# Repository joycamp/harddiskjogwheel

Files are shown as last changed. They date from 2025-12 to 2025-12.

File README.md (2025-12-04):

# Hard Disk Jog Wheel

Turn a hard disk drive (or any rotary mechanism) into a wireless MIDI jog wheel for video or audio editing using an ESP32-S3 and AS5600 magnetic encoder.

This project creates a Bluetooth Low Energy (BLE) MIDI device that sends relative jog wheel commands compatible with Logic Pro, Final Cut Pro (via Command Post), and other DAWs.

## Features

- **Wireless BLE MIDI** - No cables needed, works with macOS Audio MIDI Setup
- **AS5600 Magnetic Encoder** - Contactless, high-resolution rotation sensing
- **Relative MIDI Mode** - Proper jog wheel behavior with proportional speed control
- **Button Support** - Additional MIDI CC for button press/release
- **Configurable Sensitivity** - Adjustable rotation thresholds and scaling

## Hardware Requirements

- **ESP32-S3** development board (e.g., ESP32-S3-DevKitC-1)
- **AS5600** magnetic position sensor (AMS AS5600)
- **Magnet** - Diametrically magnetized magnet (typically 6-8mm diameter, 2-3mm thick)
- **Button** - Optional tactile button for additional control
- **Wiring** - Jumper wires, breadboard (or custom PCB)

## Hardware Connections

### AS5600 Magnetic Encoder
- **VCC** → 3.3V (ESP32-S3)
- **GND** → GND (ESP32-S3)
- **SDA** → GPIO 8
- **SCL** → GPIO 9

**Note:** The AS5600 operates at 3.3V logic levels, which matches the ESP32-S3 perfectly. No level shifters needed.

### Button (Optional)
- **One terminal** → GPIO 4
- **Other terminal** → GND

The code uses internal pull-up resistors, so no external pull-up needed.

### Magnet Positioning
- Place magnet **1-3mm** above the AS5600 sensor
- Ensure magnet is **centered** over the sensor
- Magnet should be **diametrically magnetized** (north-south poles on opposite sides)

## Software Setup

### 1. Install Arduino IDE

Download and install [Arduino IDE](https://www.arduino.cc/en/software) (version 1.8.19 or later).

### 2. Install ESP32-S3 Board Support

1. Open Arduino IDE
2. Go to **File > Preferences**
3. In "Additional Board Manager URLs", add:
   ```
   https://espressif.github.io/arduino-esp32/package_esp32_index.json
   ```
4. Go to **Tools > Board > Boards Manager**
5. Search for "ESP32" and install **"esp32 by Espressif Systems"** (version 3.3.3 or later)
6. Select your board: **Tools > Board > ESP32 Arduino > ESP32S3 Dev Module**

### 3. Install Required Libraries

Install these libraries via **Tools > Manage Libraries**:

#### Required Libraries:

1. **ESP32-BLE-MIDI** by max22-
   - Search for "ESP32-BLE-MIDI" in Library Manager
   - Install version compatible with ESP32-S3
   - GitHub: https://github.com/max22-/ESP32-BLE-MIDI

2. **NimBLE-Arduino** by h2zero
   - Search for "NimBLE-Arduino" in Library Manager
   - Install latest version
   - Required dependency for ESP32-BLE-MIDI
   - GitHub: https://github.com/h2zero/NimBLE-Arduino

#### Built-in Libraries (No Installation Needed):
- **Wire** - I2C communication (included with ESP32 core)
- **Arduino.h** - Core Arduino functions (included with ESP32 core)

### 4. Configure Board Settings

In Arduino IDE, configure these settings:

- **Tools > Board** → **ESP32S3 Dev Module**
- **Tools > USB Mode** → **Hardware CDC and JTAG** (for Serial debugging)
- **Tools > USB CDC On Boot** → **Enabled**
- **Tools > Partition Scheme** → **Default 4MB with spiffs** (or **Huge APP**)
- **Tools > Port** → Select your ESP32-S3 COM port

### 5. Upload the Sketch

1. Open `midijogwheelV2.ino` in Arduino IDE
2. Verify all settings are correct
3. Click **Upload**

**If upload fails:**
- Hold **BOOT** button on ESP32-S3
- Press and release **RESET** button
- Release **BOOT** button
- Immediately click Upload in Arduino IDE

### 6. Connect via Bluetooth

1. Open **Audio MIDI Setup** (Applications > Utilities on macOS)
2. Go to **Window > Show MIDI Studio**
3. Click the **"Configure Bluetooth"** icon (or go to **Window > Configure Bluetooth**)
4. Find **"ESP32-S3-TE!"** in the list
5. Click **Connect**

The device should now appear in your MIDI Studio and be available to Logic Pro, Final Cut Pro, and other applications.

## Configuration

### MIDI Settings

Edit these constants in `midijogwheelV2.ino`:

```cpp
const int MIDI_CHANNEL = 0;  // MIDI channel (0-15, 0 = channel 1)
const int JOG_CC = 60;       // CC number for jog wheel
const int BUTTON_CC = 61;    // CC number for button
```

### Sensitivity Settings

Adjust rotation sensitivity:

```cpp
const int ANGLE_THRESHOLD = 10;        // Minimum angle change to trigger MIDI (0-4095 scale)
const int MIN_RELATIVE_VALUE = 1;      // Minimum relative increment
const int MAX_RELATIVE_VALUE = 10;     // Maximum relative increment (lower = less sensitive)
const int RELATIVE_SCALE = 20;         // Scale factor (higher = less sensitive)
```

**Tips:**
- Lower `MAX_RELATIVE_VALUE` (e.g., 5) = less sensitive to fast spinning
- Higher `RELATIVE_SCALE` (e.g., 30) = overall less sensitive
- Lower `ANGLE_THRESHOLD` (e.g., 5) = more responsive to small movements

### Pin Configuration

If you need different GPIO pins:

```cpp
const int SDA_PIN = 8;      // AS5600 SDA pin
const int SCL_PIN = 9;      // AS5600 SCL pin
const int BUTTON_PIN = 4;   // Button pin
```

**Note:** ESP32-S3 supports I2C on any GPIO pins. Choose pins that don't conflict with your board's USB/JTAG pins.

### Device Name

Change the BLE device name:

```cpp
BLEMidiServer.begin("ESP32-S3-TE!");  // Change to your preferred name
```

**Note:** Keep the name short (max 29 characters) and avoid special characters that might cause issues.

## MIDI Protocol

### Jog Wheel (CC 60)

Uses **relative mode encoding**:
- **Clockwise rotation**: CC 60 = 1-63 (increment values, proportional to rotation speed)
- **Counter-clockwise rotation**: CC 60 = 65-127 (decrement values, proportional to rotation speed)
- **No movement**: No MIDI messages sent

Values scale with rotation speed:
- Slow rotation → small values (1-2 or 65-66)
- Fast rotation → larger values (up to MAX_RELATIVE_VALUE or 64+MAX_RELATIVE_VALUE)

### Button (CC 61)

- **Press**: CC 61 = 127
- **Release**: CC 61 = 0

## Usage with DAWs

### Logic Pro

1. Open Logic Pro
2. Go to **Logic Pro > Settings > MIDI**
3. Ensure your ESP32-S3 device is enabled
4. Use **Learn** function:
   - Right-click on transport controls or jog wheel
   - Select **"Learn MIDI Assignment"**
   - Rotate the jog wheel
   - Logic Pro will learn the MIDI CC message

### Final Cut Pro (via Command Post)

1. Install [Command Post](https://commandpost.fcp.cafe/)
2. Open Command Post preferences
3. Go to **MIDI** settings
4. Click **Learn** for the action you want to map
5. Rotate the jog wheel
6. Command Post will learn the MIDI assignment

**Note:** Ensure the device name in Command Post matches exactly what your ESP32-S3 advertises (default: "ESP32-S3-TE!").

### Other DAWs

Any DAW that supports MIDI CC learning should work. The device sends standard MIDI Control Change messages over BLE MIDI.

## Testing

### Serial Monitor

Open Serial Monitor (115200 baud) to see:
- AS5600 initialization status
- Angle readings and changes
- MIDI messages being sent
- Connection status

## Troubleshooting

### Device Not Appearing in Bluetooth Settings

- Ensure BLE MIDI is initialized (check Serial Monitor)
- Try disconnecting and reconnecting in Audio MIDI Setup
- Restart Audio MIDI Setup
- Check that no other device is using the same name

### AS5600 Not Responding (I2C Error)

- Check wiring: VCC→3.3V, GND→GND, SDA→GPIO8, SCL→GPIO9
- Verify magnet is positioned 1-3mm above sensor
- Check Serial Monitor for specific error codes
- Verify I2C address 0x36 is accessible (you can use any I2C scanner tool)

### MIDI Messages Not Working in DAW

- Verify device is connected in Audio MIDI Setup
- Check MIDI channel matches what DAW expects (default: channel 1)
- Ensure DAW has MIDI input enabled
- Try learning the MIDI assignment again
- Check Serial Monitor to confirm messages are being sent

### Too Sensitive / Not Sensitive Enough

- Adjust `MAX_RELATIVE_VALUE` (lower = less sensitive to fast spinning)
- Adjust `RELATIVE_SCALE` (higher = overall less sensitive)
- Adjust `ANGLE_THRESHOLD` (lower = more responsive)

### Upload Fails

- Use manual bootloader mode (hold BOOT, press RESET, release BOOT, upload)
- Try different USB cable (some are power-only)
- Try different USB port
- Close Serial Monitor before uploading
- Ensure no other program is using the serial port

## Project Structure

```
harddiskjogwheel/
├── midijogwheelV2.ino          # Main sketch
├── README.md                    # This file
├── LICENSE                      # MIT License
├── serial_monitor.py           # Python serial monitor script (optional)
└── .gitignore                  # Git ignore rules
```

## Libraries Used

### ESP32-BLE-MIDI
- **Author**: max22-
- **Purpose**: BLE MIDI server implementation for ESP32
- **Installation**: Arduino Library Manager → Search "ESP32-BLE-MIDI"
- **GitHub**: https://github.com/max22-/ESP32-BLE-MIDI
- **License**: Check repository for license information

### NimBLE-Arduino
- **Author**: h2zero
- **Purpose**: NimBLE BLE stack for Arduino/ESP32 (dependency of ESP32-BLE-MIDI)
- **Installation**: Arduino Library Manager → Search "NimBLE-Arduino"
- **GitHub**: https://github.com/h2zero/NimBLE-Arduino
- **License**: Apache 2.0

### Wire (Built-in)
- **Purpose**: I2C communication library
- **Included**: With ESP32 Arduino core
- **Documentation**: https://www.arduino.cc/reference/en/language/functions/communication/wire/

## License

MIT License - See LICENSE file for details.

## Credits

- ESP32-S3 by Espressif Systems
- AS5600 by AMS (Austria Micro Systems)
- ESP32-BLE-MIDI library by max22-
- NimBLE-Arduino by h2zero

## Contributing

Contributions welcome! Please open an issue or pull request on GitHub.

## Support

For issues, questions, or contributions, please use the GitHub Issues page.

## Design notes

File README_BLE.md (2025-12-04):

# BLE MIDI Setup for ESP32-S3

This version uses Bluetooth Low Energy (BLE) MIDI instead of USB MIDI, which works well on macOS/iOS.

## Library Installation

1. **Install ESP32-BLE-MIDI Library:**
   - Go to **Tools > Manage Libraries**
   - Search for "ESP32-BLE-MIDI"
   - Install "ESP32-BLE-MIDI" by lathoub (or max22-)

## Board Settings

- **Tools > USB Mode** → Can be "Hardware CDC and JTAG" (Serial will work!)
- **Tools > USB CDC On Boot** → "Enabled"

## Setup Steps

1. **Upload the BLE MIDI code** (`minimal_test_ble.ino`)

2. **Pair with macOS:**
   - Open **System Settings > Bluetooth**
   - Look for "ESP32-S3 MIDI"
   - Click **Connect**

3. **Add to Audio MIDI Setup:**
   - Open **Audio MIDI Setup** (Applications > Utilities)
   - Go to **Window > Show MIDI Studio**
   - The device should appear automatically after pairing
   - If not, click **"Rescan MIDI"**

4. **Test:**
   - Open Serial Monitor (115200 baud) to see status
   - The device sends CC60 = 1 every second when connected
   - Check Audio MIDI Setup to verify messages are being received

## Advantages of BLE MIDI

- ✅ Works wirelessly
- ✅ Native macOS/iOS support
- ✅ Serial debugging works (unlike USB-OTG mode)
- ✅ More reliable than USB MIDI on some boards
- ✅ Can connect to multiple devices

## Notes

- The device name is "ESP32-S3 MIDI" - look for this in Bluetooth settings
- You may need to pair it first in Bluetooth settings before it appears in MIDI Studio
- BLE MIDI has slightly higher latency than USB MIDI, but usually not noticeable

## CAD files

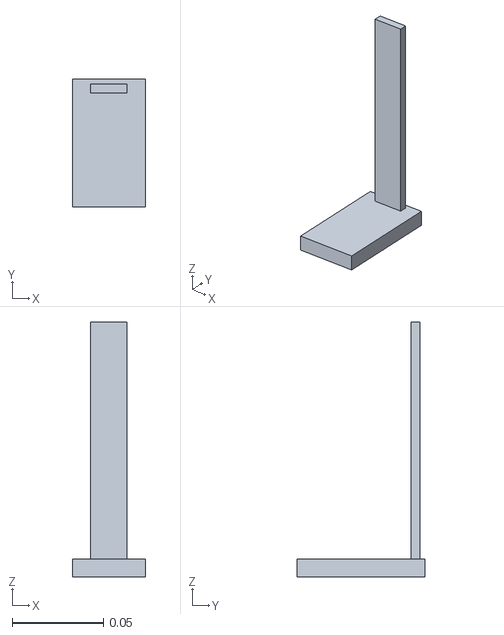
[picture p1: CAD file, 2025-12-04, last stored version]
models/armatureV3.obj
0.04 x 0.07 x 0.14

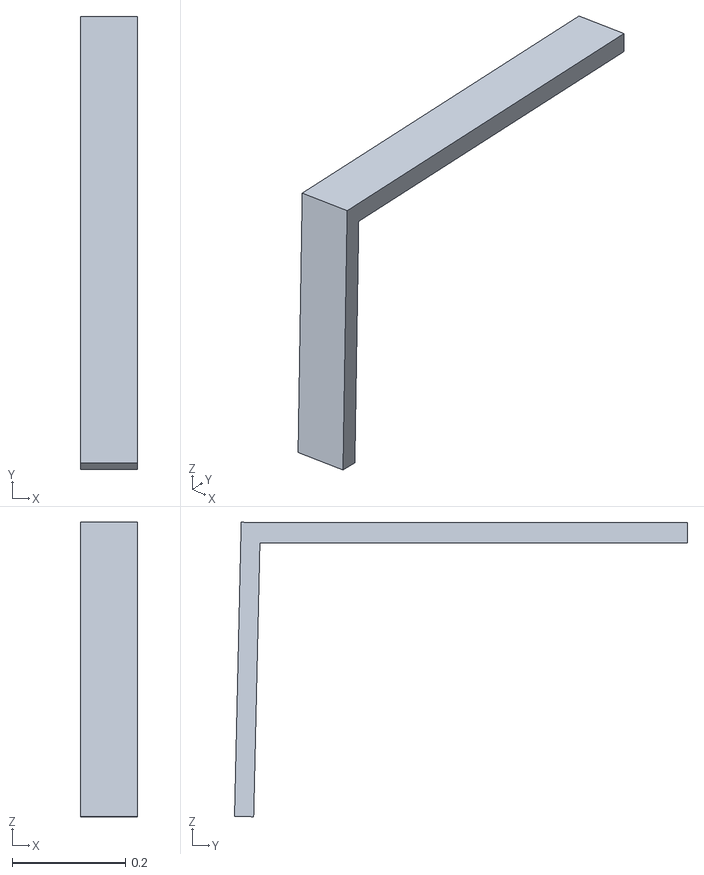
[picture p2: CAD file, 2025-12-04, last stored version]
models/armature2.stl
0.1 x 0.8 x 0.521

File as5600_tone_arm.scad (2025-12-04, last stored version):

//
// HDD jog wheel "tone arm" for Adafruit AS5600 (Adafruit 6357)
// Arm mounts at the left screw hole, treated as (0, 0)
// Spindle centre is at (spindle_dx, spindle_dy)
//
// All units in millimetres
//

// --------------------------
// Geometry inputs
// --------------------------

// Height from HDD lid to magnet top
magnet_above_lid = 3;          // 3 mm magnet on the hub

// Sensor gap you want between chip and magnet
sensor_gap = 2;                // 1 to 3 mm is ideal

// Board dimensions for Adafruit 6357 (approx, tweak if needed)
board_x = 20;   // along arm
board_y = 18;   // across arm
pcb_thickness = 1.6;
chip_above_pcb = 1.0;          // distance chip body top above PCB

// Tone arm geometry
arm_outer_diameter  = 8;
arm_inner_diameter  = 4;
headshell_length    = 26;      // region under sensor
headshell_width     = 22;
headshell_thickness = 3;

// Mount block geometry
base_block_length   = 26;
base_block_width    = 24;
base_block_height   = 10;
mount_hole_diameter = 3.5;     // M3 screw

// --------------------------
// Position of spindle relative to screw hole
// X to the right, Y up when looking at the lid
// Your measurements:
//   X = 65 mm
//   Y = 20 mm
// --------------------------

spindle_dx = 65;
spindle_dy = 20;

// --------------------------
// Derived heights
// --------------------------

// Magnet top relative to lid plane
magnet_top_z = magnet_above_lid;

// Chip height
chip_z       = magnet_top_z + sensor_gap;

// PCB bottom height so chip lands at chip_z
pcb_bottom_z = chip_z - chip_above_pcb - pcb_thickness / 2;

// Place underside of headshell just above PCB
headshell_z  = pcb_bottom_z + headshell_thickness / 2;

// Arm tube centre height
arm_centre_z = headshell_z + 2;   // small offset above headshell

// --------------------------
// Helper modules
// --------------------------

module arm_tube(length, od, id) {
    difference() {
        rotate([0,90,0])
            cylinder(h = length, r = od/2, center = true, $fn = 48);
        rotate([0,90,0])
            cylinder(h = length + 0.5, r = id/2, center = true, $fn = 48);
    }
}

module base_block() {
    // Block extends out in +X from the screw hole at (0,0)
    translate([base_block_length/2, 0, base_block_height/2])
        cube([base_block_length, base_block_width, base_block_height], center = true);

    // Mount hole at origin down through the block
    translate([0, 0, base_block_height/2])
        cylinder(h = base_block_height + 2,
                 d = mount_hole_diameter,
                 center = true, $fn = 32);
}

module headshell() {
    translate([spindle_dx, spindle_dy, headshell_z])
        cube([headshell_length, headshell_width, headshell_thickness],
             center = true);
}

module as5600_pocket() {
    // Slightly oversized pocket for the PCB inside the headshell
    pocket_x = board_x + 1;
    pocket_y = board_y + 1;
    pocket_z = headshell_thickness - 0.8;   // thin roof

    translate([spindle_dx, spindle_dy,
               pcb_bottom_z + pocket_z/2])
        cube([pocket_x, pocket_y, pocket_z], center = true);
}

// --------------------------
// Main arm
// --------------------------

module tone_arm() {
    difference() {
        union() {
            // Base mount at screw hole
            base_block();

            // Arm tube from block to headshell
            arm_start_x = base_block_length;             // from just ahead of screw
            arm_end_x   = spindle_dx - headshell_length/2;
            arm_len     = arm_end_x - arm_start_x;

            translate([(arm_start_x + arm_end_x) / 2,
                       spindle_dy / 2,
                       arm_centre_z])
                arm_tube(arm_len, arm_outer_diameter, arm_inner_diameter);

            // Small support between block and arm
            translate([base_block_length / 2 + 3,
                       spindle_dy / 2,
                       arm_centre_z / 2])
                cube([6, 10, arm_centre_z], center = true);

            // Headshell
            headshell();
        }

        // Cut PCB pocket
        as5600_pocket();
    }
}

// --------------------------
// Preview helpers
// --------------------------

$fn = 64;

// Show HDD lid as a plane at z = 0
color([0.8,0.8,0.8,0.3])
translate([0,0,-0.5])
cube([140, 140, 1], center = true);

// Screw hole marker at origin
color("blue")
translate([0,0,0])
cylinder(h = 2, d = 5, center = true);

// Spindle centre marker and magnet top
color("red")
translate([spindle_dx, spindle_dy, magnet_top_z])
cylinder(h = 1, d = 8, center = true);

// Tone arm
color("silver")
tone_arm();

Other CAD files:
models/armature.blend
models/armature2.blend
models/armaturev3.blend

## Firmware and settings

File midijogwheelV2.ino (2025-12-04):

/*
 * MIDI Jog Wheel Controller for ESP32-S3
 * Reads AS5600 magnetic encoder rotation and button state
 * Sends MIDI CC messages over BLE MIDI (Bluetooth Low Energy)
 * 
 * Hardware Connections:
 * - AS5600 VCC -> 3.3V
 * - AS5600 GND -> GND
 * - AS5600 SDA -> GPIO 8
 * - AS5600 SCL -> GPIO 9
 * - Button -> GPIO pin (configurable, default: GPIO 4)
 * 
 * Libraries Required:
 * - ESP32-BLE-MIDI by max22- (install via Arduino Library Manager)
 * - NimBLE-Arduino by h2zero (install via Arduino Library Manager)
 * 
 * Board Settings:
 * - Tools > USB Mode → Hardware CDC and JTAG (for Serial debugging)
 * - Tools > USB CDC On Boot → Enabled
 * - Tools > Partition Scheme → Default 4MB with spiffs (or Huge APP)
 * 
 * MIDI Configuration:
 * - CW rotation sends: CC 60 = 65 (relative mode +1)
 * - CCW rotation sends: CC 60 = 63 (relative mode -1)
 * - Button press sends: CC 61 = 127
 * - Button release sends: CC 61 = 0
 * 
 * Connection:
 * 1. Upload this sketch to ESP32-S3
 * 2. Open Audio MIDI Setup (Applications > Utilities)
 * 3. Go to Window > Show MIDI Studio
 * 4. Click "Configure Bluetooth" icon
 * 5. Find "ESP32-S3 MIDI Jog Wheel" and click Connect
 */

#include <Arduino.h>
#include <BLEMidi.h>
#include <Wire.h>

// AS5600 I2C Configuration
#define AS5600_I2C_ADDR 0x36
#define AS5600_REG_RAW_ANGLE 0x0C  // 12-bit raw angle (0-4095)
#define AS5600_REG_MAGNITUDE 0x1B  // Magnet strength

// I2C Pin Definitions
const int SDA_PIN = 8;   // AS5600 SDA pin
const int SCL_PIN = 9;   // AS5600 SCL pin

// Button pin
const int BUTTON_PIN = 4;  // GPIO pin for button

// MIDI Configuration
// BLE MIDI library uses 1-16 for channels (1 = MIDI channel 1, 2 = MIDI channel 2, etc.)
// If monitor shows wrong channel, adjust this value (1-16)
const int MIDI_CHANNEL = 1;  // MIDI channel (1-16, where 1 = MIDI channel 1)
const int JOG_CC = 60;       // CC number for jog wheel
const int BUTTON_CC = 61;    // CC number for button
// Relative mode encoding for Logic Pro:
// Values 1-63 = increment (positive), Values 65-127 = decrement (negative)
// Value 64 = no change (never send this)
// We send constant values: 1 for CW, 65 for CCW (not proportional to speed)
const int CW_VALUE = 1;       // Clockwise rotation value
const int CCW_VALUE = 65;    // Counter-clockwise rotation value

// AS5600 angle tracking
uint16_t lastAngle = 0;
uint16_t smoothedAngle = 0;  // Smoothed angle value for direction detection
bool angleInitialized = false;  // Track if we've initialized smoothing
const int ANGLE_THRESHOLD = 10;  // Minimum smoothed angle change to trigger MIDI (0-4095 scale)

// Movement accumulator to ignore small initial touches
int movementAccumulator = 0;  // Accumulates movement in current direction
int lastDirection = 0;  // Last movement direction: 1 = positive, -1 = negative, 0 = none
const int MOVEMENT_THRESHOLD = 30;  // Minimum cumulative movement before sending MIDI (prevents accidental touches)

// Direction lock to prevent rapid direction changes
int lockedDirection = 0;  // Currently locked direction: 1 = positive, -1 = negative, 0 = none
int oppositeDirectionAccumulator = 0;  // Accumulates movement in opposite direction
int consecutiveOppositeSamples = 0;  // Count consecutive samples in opposite direction
unsigned long directionLockTime = 0;  // When direction was locked
const int DIRECTION_CHANGE_THRESHOLD = 300;  // Must accumulate this much in opposite direction before switching
const int MIN_CONSECUTIVE_OPPOSITE = 10;  // Require this many consecutive opposite samples before even accumulating
const unsigned long MIN_LOCK_TIME_MS = 500;  // Direction must be locked for this long before allowing change
unsigned long lastOppositeMovementTime = 0;  // Track when last opposite movement occurred
const unsigned long OPPOSITE_DECAY_TIME_MS = 500;  // If no opposite movement for this long, reset accumulator

// Smoothing configuration - used only to detect direction reliably
const float SMOOTHING_FACTOR = 0.2;  // 0.0-1.0, lower = more smoothing (0.2 = 20% new, 80% old)
const unsigned long MAX_SAMPLE_TIME_MS = 100;  // Maximum time between samples to reset (prevents large jumps)
const int MAX_ANGLE_CHANGE_PER_SAMPLE = 500;  // Maximum angle change per sample (safety limit)

// Button state variables
int lastButtonState = HIGH;  // Button is HIGH when not pressed (pull-up)

// Button debounce variables
unsigned long lastButtonDebounceTime = 0;
const unsigned long BUTTON_DEBOUNCE_DELAY = 50;

// Helper function to send MIDI Control Change message
void sendMIDICC(uint8_t channel, uint8_t control, uint8_t value) {
  // Only send if BLE MIDI is connected
  if (BLEMidiServer.isConnected()) {
    // BLE MIDI library uses 1-16 for channels
    // channel parameter is already 1-16, pass it directly
    BLEMidiServer.controlChange(channel, control, value);
  }
}

// Read a register from AS5600 via I2C
uint8_t readRegister(uint8_t regAddr) {
  // Add small delay to prevent bus issues
  delayMicroseconds(100);
  
  Wire.beginTransmission(AS5600_I2C_ADDR);
  Wire.write(regAddr);
  uint8_t error = Wire.endTransmission();
  
  if (error != 0) {
    // Log error details occasionally
    static unsigned long lastI2CError = 0;
    if (millis() - lastI2CError > 5000) {
      Serial.print("I2C Error: ");
      Serial.print(error);
      Serial.print(" (0=OK, 1=data too long, 2=NACK addr, 3=NACK data, 4=other)");
      Serial.print(" | Address: 0x");
      Serial.print(AS5600_I2C_ADDR, HEX);
      Serial.print(" | Register: 0x");
      Serial.print(regAddr, HEX);
      Serial.print(" | Try: Check wiring, pull-up resistors, power");
      Serial.println();
      lastI2CError = millis();
    }
    return 0xFF; // Error indicator
  }
  
  // Small delay before requesting data
  delayMicroseconds(100);
  
  uint8_t bytesRequested = Wire.requestFrom(AS5600_I2C_ADDR, 1, true); // true = stop after request
  if (bytesRequested == 1 && Wire.available()) {
    return Wire.read();
  }
  
  // No data available
  static unsigned long lastI2CError = 0;
  if (millis() - lastI2CError > 5000) {
    Serial.print("I2C Error: No data available | Requested: ");
    Serial.print(bytesRequested);
    Serial.print(" | Available: ");
    Serial.println(Wire.available());
    lastI2CError = millis();
  }
  return 0xFF;
}

// Read a 16-bit register (high byte first) - AS5600 specific
uint16_t readRegister16(uint8_t regAddr) {
  // AS5600 16-bit registers are read as two consecutive bytes
  // Read both bytes in a single I2C transaction for better reliability
  delayMicroseconds(100);
  
  Wire.beginTransmission(AS5600_I2C_ADDR);
  Wire.write(regAddr);
  uint8_t error = Wire.endTransmission();
  
  if (error != 0) {
    return 0xFFFF; // Error indicator
  }
  
  delayMicroseconds(100);
  
  // Request 2 bytes (high byte, then low byte)
  uint8_t bytesRequested = Wire.requestFrom(AS5600_I2C_ADDR, 2, true);
  if (bytesRequested == 2 && Wire.available() >= 2) {
    uint8_t highByte = Wire.read();
    uint8_t lowByte = Wire.read();
    return (highByte << 8) | lowByte;
  }
  
  return 0xFFFF; // Error indicator
}

// Reset I2C bus - useful if bus gets locked up
void resetI2CBus() {
  Wire.end();
  delay(10);
  Wire.begin(SDA_PIN, SCL_PIN);
  Wire.setClock(50000);
  Wire.setTimeout(1000);
}

// Read raw angle from AS5600 (0-4095)
uint16_t readRawAngle() {
  uint16_t result = readRegister16(AS5600_REG_RAW_ANGLE);
  
  // If we get repeated errors, try resetting the bus
  static int errorCount = 0;
  if (result == 0xFFFF) {
    errorCount++;
    if (errorCount > 10) {
      Serial.println("Resetting I2C bus due to repeated errors...");
      resetI2CBus();
      errorCount = 0;
      delay(50); // Give bus time to stabilize
    }
  } else {
    errorCount = 0; // Reset counter on successful read
  }
  
  return result;
}

// Read magnet magnitude (strength) from AS5600
uint16_t readMagnitude() {
  return readRegister16(AS5600_REG_MAGNITUDE);
}

void setup() {
  // Initialize Serial for debugging
  Serial.begin(115200);
  delay(2000);
  Serial.println("\n========================================");
  Serial.println("MIDI Jog Wheel Controller");
  Serial.println("ESP32-S3 BLE MIDI + AS5600 Version");
  Serial.println("Version: 2.1 - Constant Values (1/65)");
  Serial.println("========================================");
  
  // Initialize I2C for AS5600
  Serial.println("Initializing I2C for AS5600...");
  Wire.begin(SDA_PIN, SCL_PIN);
  // Try slower I2C speed - AS5600 can be sensitive to timing
  Wire.setClock(50000); // 50kHz I2C speed (slower, more reliable)
  // Set I2C timeout to prevent hanging
  Wire.setTimeout(1000); // 1 second timeout
  Serial.print("SDA Pin: "); Serial.println(SDA_PIN);
  Serial.print("SCL Pin: "); Serial.println(SCL_PIN);
  Serial.print("I2C Address: 0x"); Serial.println(AS5600_I2C_ADDR, HEX);
  Serial.print("I2C Clock: 50kHz");
  
  // Scan I2C bus to see what devices are present
  Serial.println("\nScanning I2C bus...");
  byte devicesFound = 0;
  for (byte address = 1; address < 127; address++) {
    Wire.beginTransmission(address);
    byte error = Wire.endTransmission();
    
    if (error == 0) {
      Serial.print("  I2C device found at address 0x");
      if (address < 16) Serial.print("0");
      Serial.print(address, HEX);
      if (address == AS5600_I2C_ADDR) {
        Serial.println(" <- AS5600 (expected)");
      } else {
        Serial.println();
      }
      devicesFound++;
    } else if (error == 4) {
      Serial.print("  Unknown error at address 0x");
      if (address < 16) Serial.print("0");
      Serial.println(address, HEX);
    }
  }
  
  if (devicesFound == 0) {
    Serial.println("  ⚠ No I2C devices found!");
    Serial.println("  Check wiring: SDA->GPIO8, SCL->GPIO9, VCC->3.3V, GND->GND");
  } else {
    Serial.print("  Found ");
    Serial.print(devicesFound);
    Serial.println(" device(s)");
  }
  
  // Test AS5600 connection
  delay(100);
  Serial.println("\nTesting AS5600 communication...");
  uint16_t testAngle = readRawAngle();
  uint16_t testMagnitude = readMagnitude();
  
  if (testAngle == 0xFFFF) {
    Serial.println("⚠ WARNING: Could not read from AS5600!");
    Serial.println("Check wiring: VCC->3.3V, GND->GND, SDA->GPIO8, SCL->GPIO9");
    Serial.println("Verify magnet is positioned 1-3mm above sensor");
  } else {
    Serial.print("✓ AS5600 detected! Initial angle: ");
    Serial.println(testAngle);
    Serial.print("  Magnet magnitude: ");
    Serial.println(testMagnitude);
    if (testMagnitude < 100) {
      Serial.println("  ⚠ WARNING: Magnet may be too weak or too far!");
    }
    lastAngle = testAngle;
  }
  
  // Configure button pin
  Serial.println("Configuring button pin...");
  pinMode(BUTTON_PIN, INPUT_PULLUP);
  lastButtonState = digitalRead(BUTTON_PIN);
  
  // Initialize BLE MIDI
  Serial.println("Initializing BLE MIDI...");
  BLEMidiServer.begin("ESP32-S3-TE!");
  Serial.println("BLE MIDI initialized");
  Serial.println("Device name: ESP32-S3 MIDI Jog Wheel");
  Serial.println("\nTo connect:");
  Serial.println("1. Open Audio MIDI Setup");
  Serial.println("2. Window > Show MIDI Studio");
  Serial.println("3. Click 'Configure Bluetooth'");
  Serial.println("4. Find 'ESP32-S3 MIDI Jog Wheel' and Connect");
  Serial.println("========================================\n");
  
  Serial.println("Setup complete! Waiting for BLE connection...");
  Serial.println("Rotate wheel or press button to test (after connecting)\n");
}

void loop() {
  // Check connection status (only log when it changes)
  static bool lastConnectionState = false;
  bool isConnected = BLEMidiServer.isConnected();
  
  if (isConnected != lastConnectionState) {
    Serial.print("BLE MIDI: ");
    Serial.println(isConnected ? "CONNECTED" : "DISCONNECTED");
    lastConnectionState = isConnected;
  }
  
  // Process encoder/button regardless of connection (for testing)
  // MIDI will only be sent if connected
  {
    // Connection is logged above when status changes
    
    // Track time for rate limiting
    static unsigned long lastSampleTime = 0;
    unsigned long currentTime = millis();
    unsigned long timeDelta = currentTime - lastSampleTime;
    
    // Read current angle from AS5600
    uint16_t currentAngle = readRawAngle();
    
    // Check if read was successful
    if (currentAngle == 0xFFFF) {
      // I2C read failed - log occasionally
      static unsigned long lastErrorTime = 0;
      if (millis() - lastErrorTime > 5000) {
        Serial.println("⚠ ERROR: Failed to read from AS5600 (I2C error)");
        lastErrorTime = millis();
      }
    } else {
      // Apply exponential smoothing to reduce noise and detect direction reliably
      if (!angleInitialized) {
        // First reading - initialize smoothed value
        smoothedAngle = currentAngle;
        lastAngle = currentAngle;
        angleInitialized = true;
        lastSampleTime = currentTime;
        // Angle initialized silently
      } else {
        // Reset if too much time has passed (prevents large jumps from delays)
        if (timeDelta > MAX_SAMPLE_TIME_MS) {
          smoothedAngle = currentAngle;
          lastAngle = currentAngle;
          lastSampleTime = currentTime;
        } else {
          // Apply exponential smoothing: smoothed = (1-alpha) * old + alpha * new
          // Using floating point for accuracy, then convert to uint16_t
          float newSmoothed = (1.0 - SMOOTHING_FACTOR) * smoothedAngle + SMOOTHING_FACTOR * currentAngle;
          smoothedAngle = (uint16_t)round(newSmoothed);
          
          // Calculate angle change from smoothed values, handling wrap-around at 0/4095 boundary
          int angleChange = (int)smoothedAngle - (int)lastAngle;
          
          // Handle wrap-around: if change is > 2048, assume wrap-around in CCW direction
          if (angleChange > 2048) {
            angleChange = angleChange - 4096;
          }
          // Handle wrap-around: if change is < -2048, assume wrap-around in CW direction
          else if (angleChange < -2048) {
            angleChange = angleChange + 4096;
          }
          
          // Safety limit: prevent huge values from calculation errors
          if (angleChange > MAX_ANGLE_CHANGE_PER_SAMPLE) {
            angleChange = MAX_ANGLE_CHANGE_PER_SAMPLE;
          } else if (angleChange < -MAX_ANGLE_CHANGE_PER_SAMPLE) {
            angleChange = -MAX_ANGLE_CHANGE_PER_SAMPLE;
          }
          
          // Only process if smoothed change exceeds threshold (to avoid noise)
          if (abs(angleChange) >= ANGLE_THRESHOLD) {
            int currentDirection = (angleChange > 0) ? 1 : -1;
            
            // Direction lock logic: prevent rapid direction changes
            if (lockedDirection == 0) {
              // No direction locked yet - establish one
              lockedDirection = currentDirection;
              directionLockTime = currentTime;
              movementAccumulator += abs(angleChange);
              oppositeDirectionAccumulator = 0;
            } else if (currentDirection == lockedDirection) {
              // Same direction as locked - accumulate normally
              movementAccumulator += abs(angleChange);
              oppositeDirectionAccumulator = 0;  // Reset opposite direction accumulator
              consecutiveOppositeSamples = 0;  // Reset consecutive opposite counter
              lastOppositeMovementTime = 0;  // Reset opposite movement timer
            } else {
              // Opposite direction detected
              // Only allow direction change if direction has been locked for minimum time
              if ((currentTime - directionLockTime) < MIN_LOCK_TIME_MS) {
                // Too soon to change direction - completely ignore opposite movement
                return;  // Exit early, don't process this sample at all
              }
              
              consecutiveOppositeSamples++;
              lastOppositeMovementTime = currentTime;
              
              // Only start accumulating opposite movement after multiple consecutive samples
              // This filters out single-sample noise/vibration
              if (consecutiveOppositeSamples >= MIN_CONSECUTIVE_OPPOSITE) {
                // We have enough consecutive opposite samples - start accumulating
                oppositeDirectionAccumulator += abs(angleChange);
                
                // Only switch direction if we've accumulated enough in opposite direction
                if (oppositeDirectionAccumulator >= DIRECTION_CHANGE_THRESHOLD) {
                  // Direction change confirmed - switch lock
                  lockedDirection = currentDirection;
                  directionLockTime = currentTime;  // Reset lock time
                  movementAccumulator = oppositeDirectionAccumulator - DIRECTION_CHANGE_THRESHOLD;
                  oppositeDirectionAccumulator = 0;
                  consecutiveOppositeSamples = 0;
                  lastOppositeMovementTime = 0;
                  // Continue processing with new direction
                } else {
                  // Not enough movement to change direction - completely ignore this movement
                  // CRITICAL: Don't update angle tracking - this prevents opposite movements from affecting future calculations
                  lastDirection = currentDirection;  // Track direction for decay logic
                  // Skip MIDI sending - exit this iteration early
                  return;  // Exit early, don't process this sample at all
                }
              } else {
                // Not enough consecutive opposite samples yet - completely ignore
                // Don't update angle tracking, don't accumulate, just ignore
                return;  // Exit early, don't process this sample at all
              }
            }
            
            lastDirection = currentDirection;
            
            // Decay opposite direction accumulator if no opposite movement for a while
            if (oppositeDirectionAccumulator > 0 && 
                (currentTime - lastOppositeMovementTime) > OPPOSITE_DECAY_TIME_MS) {
              oppositeDirectionAccumulator = max(0, oppositeDirectionAccumulator - 10);
              consecutiveOppositeSamples = 0;
              if (oppositeDirectionAccumulator == 0) {
                lastOppositeMovementTime = 0;
              }
            }
            
            // Only send MIDI once we've accumulated enough movement (definite spin)
            // AND we're processing in the locked direction (not accumulating opposite)
            if (movementAccumulator >= MOVEMENT_THRESHOLD) {
              if (lockedDirection > 0) {
                // Positive angle change (CW): send decrement (backward) = 65
                sendMIDICC(MIDI_CHANNEL, JOG_CC, CCW_VALUE);
                Serial.print("▶ CW | Change: ");
                Serial.print(angleChange);
                Serial.print(" | Accum: ");
                Serial.print(movementAccumulator);
                Serial.print(" | CC60 = ");
                Serial.println(CCW_VALUE);
              } else {
                // Negative angle change (CCW): send increment (forward) = 1
                sendMIDICC(MIDI_CHANNEL, JOG_CC, CW_VALUE);
                Serial.print("◀ CCW | Change: ");
                Serial.print(angleChange);
                Serial.print(" | Accum: ");
                Serial.print(movementAccumulator);
                Serial.print(" | CC60 = ");
                Serial.println(CW_VALUE);
              }
              
              // Reset accumulator after sending (but keep some to maintain responsiveness)
              movementAccumulator = movementAccumulator - MOVEMENT_THRESHOLD;
              
              // Update last angle from smoothed value (not raw)
              lastAngle = smoothedAngle;
              lastSampleTime = currentTime;
            }
          } else {
            // If movement is too small, gradually decay the accumulators
            // This prevents accidental touches from accumulating over time
            if (movementAccumulator > 0) {
              movementAccumulator = max(0, movementAccumulator - 5);
            }
            if (oppositeDirectionAccumulator > 0) {
              oppositeDirectionAccumulator = max(0, oppositeDirectionAccumulator - 5);
            }
            // Reset direction lock if both accumulators reach zero
            if (movementAccumulator == 0 && oppositeDirectionAccumulator == 0) {
              lockedDirection = 0;
              lastDirection = 0;
            }
          }
        }
      }
    }
    
    // Check for button press/release with debouncing
    int currentButtonState = digitalRead(BUTTON_PIN);
    
    if (currentButtonState != lastButtonState) {
      unsigned long currentTime = millis();
      
      // Debounce: wait a bit and check again
      if ((currentTime - lastButtonDebounceTime) > BUTTON_DEBOUNCE_DELAY) {
        currentButtonState = digitalRead(BUTTON_PIN);
        
        if (currentButtonState != lastButtonState) {
          lastButtonState = currentButtonState;
          lastButtonDebounceTime = currentTime;
          
          if (currentButtonState == LOW) {
            // Button pressed
            sendMIDICC(MIDI_CHANNEL, BUTTON_CC, 127);
            Serial.println("🔘 Button PRESSED");
          } else {
            // Button released
            sendMIDICC(MIDI_CHANNEL, BUTTON_CC, 0);
            Serial.println("🔘 Button RELEASED");
          }
        }
      }
    }
  }
  
  // Connection status is logged above when it changes
  
  delay(10); // Small delay - AS5600 doesn't need super fast polling
}

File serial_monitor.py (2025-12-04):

#!/usr/bin/env python3
"""
Simple Serial Monitor for ESP32-S3
Reads Serial output from the board
"""

import sys
import time

# Import serial at module level
try:
    import serial
    import serial.tools.list_ports
except ImportError:
    print("Error: pyserial not installed. Install with: pip3 install pyserial")
    sys.exit(1)

# Try to find the port
PORT = '/dev/cu.usbmodem23201'  # Update this if your port is different
BAUD = 115200

def main():
    print(f"Connecting to {PORT} at {BAUD} baud...")
    print("Press Ctrl+C to exit\n")
    
    ser = None
    try:
        print(f"Opening port {PORT}...")
        ser = serial.Serial(PORT, BAUD, timeout=1)
        print("Connected! Reading Serial output...\n")
        print("="*60)
        print("Press RESET button on ESP32-S3 to see boot messages")
        print("="*60 + "\n")
        
        # Wait a moment for connection to stabilize
        time.sleep(1)
        
        # Clear any stale data
        try:
            ser.reset_input_buffer()
        except:
            pass
        
        while True:
            try:
                if ser.in_waiting > 0:
                    try:
                        line = ser.readline().decode('utf-8', errors='ignore')
                        if line.strip():  # Only print non-empty lines
                            print(line.rstrip())
                            sys.stdout.flush()
                    except UnicodeDecodeError:
                        pass
            except OSError as e:
                if e.errno == 6:  # Device not configured
                    print("\n⚠ Device disconnected or not configured")
                    print("Try pressing RESET button on ESP32-S3")
                    time.sleep(1)
                    continue
                else:
                    raise
            time.sleep(0.01)
    
    except serial.SerialException as e:
        print(f"Error: {e}")
        print(f"\nTrying to find available ports...")
        try:
            ports = serial.tools.list_ports.comports()
            print("\nAvailable ports:")
            for p in ports:
                print(f"  {p.device} - {p.description}")
        except:
            pass
        if ser:
            ser.close()
        sys.exit(1)
    
    except KeyboardInterrupt:
        print("\n\nDisconnecting...")
        if ser:
            ser.close()
        sys.exit(0)

if __name__ == "__main__":
    main()

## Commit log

2025-12-04 Initial commit: ESP32-S3 BLE MIDI jog wheel with AS5600 encoder
    [armature.blend, armature2.blend, armature2.stl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]
2025-12-04 Remove 3D models directory and add to .gitignore
    [armature.blend, armature2.blend, armature2.stl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]
2025-12-04 Remove test sketches and OpenSCAD files, add to .gitignore
    [as5600_tone_arm.scad]
2025-12-04 Remove partitions.csv - not needed for this project
    [partitions.csv]
2025-12-04 Improve MIDI smoothing and direction lock for smoother scrolling
    - Add exponential smoothing to angle readings to reduce noise
    - Implement direction lock mechanism to prevent rapid direction changes
    - Add movement accumulator to ignore small initial touches
    - Require consecutive opposite samples and time-based lock before direction change
    - Increase I2C reliability with better error handling and bus reset
    - Clean up logging to only show meaningful events
    These changes significantly reduce errant MIDI messages and provide smoother, more predictable playhead movement in Logic Pro.
    [midijogwheelV2.ino]
